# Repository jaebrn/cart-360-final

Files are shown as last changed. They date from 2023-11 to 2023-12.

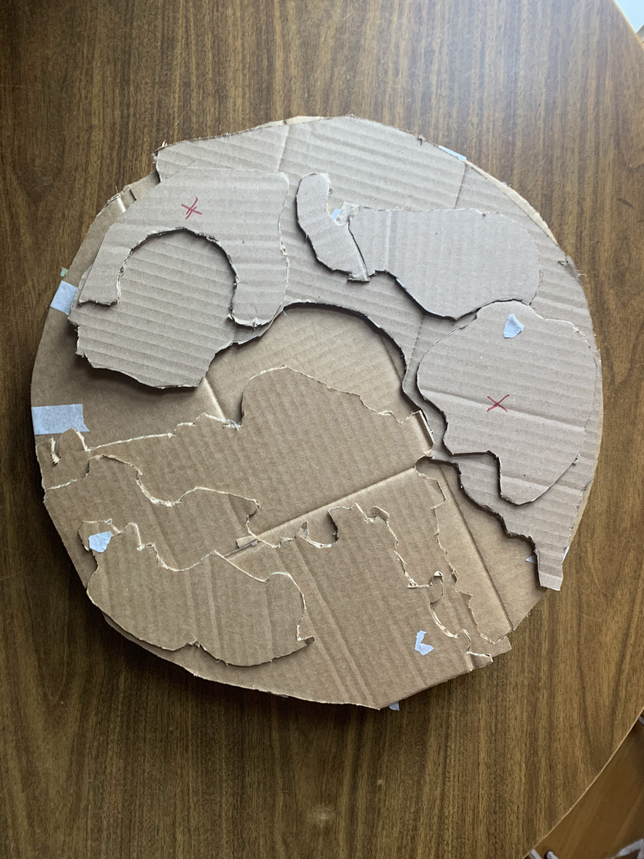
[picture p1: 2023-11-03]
Prototype/Images/Layer_4.jpg

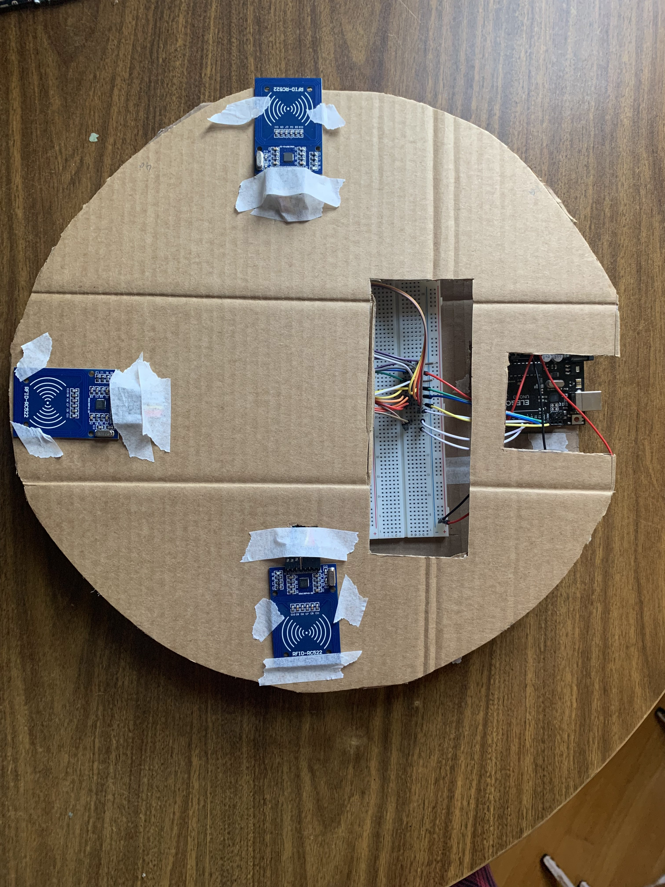
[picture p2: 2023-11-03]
Prototype/Images/Layer_2b.jpg

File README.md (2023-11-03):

# CART 360 Final

This folder includes documentation for an interactive soundscape by Kathryn Lee and Jennifer Brown, 
Completed for CART 360, Concordia University, in Fall of 2023. 

Included are various coding prototypes (progressing chronologically), proposals, sketches, writings, images and sources. 

This project is currently under development. 
Updated November 3, 2023.

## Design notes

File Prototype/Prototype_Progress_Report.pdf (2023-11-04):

# Echoes of the Land:

### Exploring the Soundscape of Pre-Colonial Montreal Through RFID-Enabled Interactive Media

### Prototype Progress Report

Documentation Website (https://github.com/jaebrn/cart-360-final) | Bibliography (https://www.zotero.org/groups/5216653/360-final/library) | Visual Design Document (https://docs.google.com/presentation/d/1SsO0nUtENjOVrvCsT_w7IpJutjQbqw8IsR_H3O8aA6U/edit?usp=sharing)

### Kathryn Lee

Computation Arts Specialization, Concordia University
Montreal, Canada
l_kathry@live.concordia.ca

### Jennifer Brown

Computation Arts Specialization, Concordia University
Montreal, Canada
br_jenni@live.concordia.ca

## Keywords

Emergent Soundscape; Interactive Design; Prototype Development; Radio Frequency Identification; Tangible Media.

## Abstract

Our goal is to create an interactive soundscape representative of pre-colonial Montreal, invoking a desire for exploration, education, and an appreciation of the natural land on which we reside.

This report details the prototyping process to date as we develop our interactive soundscape, entitled Echoes of the Land.

## Ideation, Iteration and Prototyping

Prototyping has been invaluable in our design and production process. While our initial design appeared to us as functional and easily implementable, working with our components and sensors greatly clarified the limitations we work within. Our design has evolved not only to better suit these strengths and restrictions, but to better serve our desired interaction.

Additionally, discussing our designs with others has provided us with crucial feedback, suggestions and critiques. We have learned how a tangible representation enables far greater communication of intention,
and allows for further discussion inaccessible when communicating via words and images alone. The consideration of electronics housing, internal stability, and component accessibility for troubleshooting has similarly been a significant process of ours, enabled and highlighted by the construction of a tangible prototype.

### Division of Labour

Jenna
I primarily focused on the RFID reader setup and related circuitry throughout this project. Much of my focus has been on efficiently organizing multiple readers such that they may be placed easily within the housing, use minimal Arduino pins/breadboard space, and are easily accessible for troubleshooting. Alongside this, I have been coding and experimenting with the MFRC522 Arduino library (https://github.com/miguelbalboa/rfid) (Balboa, 2012). Lastly, I have been working to maintain clean documentation, records of feedback, and citations.

Katt
I focused on the design aspects of the project. While the overall concept was thought of together, I drafted mockups and the logistics with our proposed plan and now revised prototype. I worked on compactly housing all the necessary components and built the initial prototype structure. Additionally, I have been researching other artists’ work to create a living document of our progress and to host references regarding the visual design.

## Sensors and Materiality

### Sensors and Circuitry

Within our prototype, we utilize 3 MFRC522 RFID readers (https://lastminuteengineers.com/how-rfid-works-rc522-arduino-tutorial/) connected to a singular Arduino Uno. We aim to expand this to 6 readers for our final product. As a low-fidelity example of sound output, we utilize a passive Piezo buzzer. All wired components connect to a single breadboard, embedded within the cardboard housing.

Our use of RFID results in the ability to fully obscure circuitry and components within the board. Throughout prototyping, we tested the sensor’s ability to wirelessly receive RFID tag information through varying materials of varying depths. We had great success with their ability to read through non-metallic materials like cardboard and wood up to distances of approximately 1.5 inches. While we plan on developing our final housing structure from wood, any RF-lucent material should serve our function (Payeur). Consequently, our sensors allow for a greater exploration in the visual design of the final result.

Our greatest difficulty in working with the MFRC522 reader was surrounding the implementation of multiple readers within a single microcontroller. This is a common intention amongst those working with these readers, and as such we were able to find several examples of different multi-reader implementation strategies. We primarily referenced Github user Annaane’s implementation (https://github.com/Annaane/MultiRfid) (Annaane, 2019).

Within our prototype, we attach 3 readers to the Arduino, using only 7 pins, not including power and ground, connected via SPI. Each reader uses 4 pins for communication, 2 for power/ground, and one as a reset. The interrupt pin is unused in our context. 3 of the communication pins (MISO, MOSI, SCK), and the reset pin are shared amongst the readers. A final communication pin (SDA) is uniquely connected to the microcontroller for reader identification. As such, we are able to identify the location of a placed tag and read its information. Presently we identify tags via their UID - a unique identifier defined by the tag manufacturer - with the piezo buzzer playing a unique tone for each declared UID when detected.

### Housing and Design

For our prototype, we opted for a table top display. We chose a minimalist approach to a topographical map for the design of the surface. Raised and depressed reliefs mimic the original landscape of the Montreal area. Regarding the visual design of our board and objects, we draw inspiration from Joon Moon (https://www.joonmoon.net/) and Moto Waganari (https://motowaganari.wordpress.com/) who utilize simple silhouettes and shapes within their sculptural works. Waganari is a sculpture artist whose main medium is wire work; Joon Moon is an installation artist who incorporates AR technology with light and shadow to create stunning moving images.

Keeping to the style of the board, the miniatures would take on a more geometric shape. Up until the day of the prototype presentation, it was decided the miniatures would be made out of wire. What was still unclear was how representational they would be in form. Much of our efforts were focused on the board, as it is the central object in our piece.

Given the time we had, the main concerns were with the board itself and how we can effectively communicate our idea without explicitly telling the viewer everything. During this process we tried to keep in mind what someone who has no idea about the concept would do with what we’re presenting them.

## Changes Throughout Development

The core intention of our project - to create an interactive soundscape designed to educate and foster an appreciation for Montreal’s pre-colonial environment - has been maintained throughout development. In this regard, no - our initial intention or meaning has not changed. However, there are of course more fluid elements.

Our initial design surrounded the use of a wall-mounted board to depict the landscape, constructed of a magnetic material allowing for tag-object placement anywhere upon the board. We intended to house RFIC readers underneath this magnetic board, and to visually display the pieces as ‘shadow puppets’, utilizing lighting directed up onto the board. This design includes some notable flaws, such as the RF-opacity of metallic materials and the readers’ lack of radial range (MFRC522’s are strictly effective at reading tags perpendicular to their face) (In-Depth, 2018), (Payeur, 2019). Additionally, the lighting would need to be a guaranteed distance from the tag-objects for the shadow projection to work as intended, and the vertical mounting likely would not have been conducive to our intended interaction and user experience.

Since, we have reconfigured our previous board design to consist of a tabletop piece, constructed of wood, topologically representing the island through layers of precision-cut wood. We have limited the placement options for our tag-embedded objects to a few areas cut to fit the object bases, directly above one of the several RFID readers. This design presents far fewer challenges in working with RFID technology, and allows for more exploration within the visual design of both the board and objects. Similarly, the circular, table-top nature of the design creates a more communal interaction amongst participants, and allows for greater ease of object placement.

## Bibliography

Annaane. (2019, January 19). MultiRfid. GitHub. https://github.com/Annaane/MultiRfid

Balboa, M. (2012, January). Arduino RFID Library for MFRC522. GitHub. https://github.com/miguelbalboa/rfid

Eiche, A. (2010, June 29). A Beginner’s guide to Making an Arduino Shield PCB. AaronEiche.Com.

https://aaroneiche.com/2010/06/24/a-beginners-guide-to-making-an-arduino-shield-pcb/

In-Depth: What is RFID? How It Works? Interface RC522 with Arduino. (2018, July 30). Last Minute Engineers.

https://lastminuteengineers.com/how-rfid-works-rc522-arduino-tutorial/

Ishii, H., Mazalek, A., & Lee, J. (1999). Bottles as a Minimal Interface to Access Digital Information. MIT Media Laboratory.

https://trackr-media.tangiblemedia.org/publishedmedia/Papers/466-Bottles%20as%20a%20minimal/Published/PDF

Ishii, H., Mazalek, A., Lee, J., Fletcher, R., & Paradiso, J. (1999). musicBottles. https://tangible.media.mit.edu/project/musicbottles

Joon Moon 문준용 portfolio. (n.d.). Retrieved November 4, 2023, from https://www.joonmoon.net/

Joseph, J. (2022, May). Interfacing RFID Reader With Arduino. Circuit Digest.

https://circuitdigest.com/microcontroller-projects/interfacing-rfid-reader-module-with-arduino

Lewin, J. (2012). Chandelier Harp. https://www.jenlewinstudio.com/portfolio/chandelier-harp/

MFRC522 Standard performance MIFARE and NTAG frontend. (2016). NXP Semiconductors.

https://www.nxp.com/docs/en/data-sheet/MFRC522.pdf

Miranda, E. R. (2008). Emergent songs by social robots. Journal of Experimental & Theoretical Artificial Intelligence, 20(4),

319–334. https://doi.org/10.1080/09528130701664640

Moto Waganari – artist. (n.d.). Retrieved November 4, 2023, from https://motowaganari.wordpress.com/

Payeur, C. (2019, August 22). RF-Lucent vs. RF-Opaque: Component Materials in RFID Systems. Computype.

https://www.computype.com/blog/the-importance-of-component-materials-when-constructing-rfid-systems/

Smart Lock for an Escape Room: Multi RFID Readers System. (2018, April 23). https://www.youtube.com/watch?v=ahc8Yai_sWI

Tangible, & Wu, J. (2011). jelly swarm.

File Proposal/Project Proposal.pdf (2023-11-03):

# RFID Shadow Project:

Jenna Brown & Katt Lee
Fall 2023 | CART 360 | Concordia University
Documentation GitHub (https://github.com/jaebrn/cart-360-final)

## Project Description

### Overview

The goal of this project is to create a unique, interactive piece of audio-visual public art with emergent sound qualities, reflective of the indigenous environment of Montreal. The heart of the piece is a magnetic board visually representing Montreal. Alongside this, several unique, magnetic objects, each equipped with an RFID tag, may be placed upon the board. These objects will be constructed of precisely cut wood, designed to project a shadow image when placed upon the board, which contains a strip of lighting along its bottom edge.
Each of these objects corresponds to a sound-emitting element found in Montreal throughout its history - including fauna, machinery, and humans. When placed, the board emits a corresponding sound. As objects are added, or removed, and as they remain in contact with the board over time, new and interesting audio qualities emerge, representative of the dependencies and emergent traits which form when various agents exist alongside one another in nature.

### Goal

The goal of this project is to foster within participants an appreciation for Montreal’s native wildlife through means of complex interaction and play. The various systems present within nature can often be depicted on an overly large scale, both spatially and temporally, such that it can be difficult for individuals to gain an appreciation of the elements at play and their relationships to one another. With this interactive soundscape, users can see and hear the effects of their changes in real time, creating a user-friendly model of a very broad concept. With the introduction of man and man-made elements, the project provides a greater understanding of the destructive nature of certain human impulses, while simultaneously depicting that humans themselves can and have peacefully coexisted with nature when a respect for the environment is present and prioritized.
Additionally, the interactive nature of this piece reinforces the power we each have to impart meaningful change - good or bad - on our ecosystem. The viewer is both removed from the depiction of the environment, providing them with a unique overview, while simultaneously given the opportunity to delve within, literally reaching into the landscape and shaping it.

### Audience

This project will likely be placed within a public space at Concordia University, with the target audience being students. Students by nature are curious and learning-focused, while the student body of Concordia is largely composed of out-of-province or international students. As such, the student body of Concordia is assumed to be more likely to interact with an educational art piece, and are more likely to be unfamiliar with the native landscape of Montreal. Alternatively, exiting the scope of the classroom, this project would be ideal in a location such as Montreal’s own Ecomuseum Zoo; (https://zooecomuseum.ca/en/) a conservation and education center surrounding Quebec’s indigenous wildlife.

## Sensors and Equipment

### Radio Frequency Identification (RFID)

The RFID consists of two components; the Tag and the Reader. Each Tag has a distinct UID. RFID Tags are small, inexpensive and easily embedded within a variety of objects. We plan to embed RFID tags within the magnetic, moveable objects, while implementing the reader within the board. We hope to utilize this technology to allow for identification amongst tangible objects connected to unique UIDs, which can then be called to trigger reactions through code.

### Microcontroller

Our project will be coded using the Arduino Uno. This microcontroller has many capabilities and can be used in conjunction with compatible boards such as the NFC reader. Additional positives are that it is small and compact which aids us in hiding the tech behind the experience from the audience.

### Board Composition

Our board will be housing all circuitry and major components used within this project. This includes the Arduino Uno microcontroller board, speakers, and lighting. Speakers will ideally be small and hidden around or within the board, used to play sounds associated with the specific RFID tags embedded within the magnetic objects when placed on the board.

### Magnetic Object Composition

Each moveable, magnetic object consists of a magnetic base, RFID Tag, and a small wooden structure designed to produce a shadow-image depicting the represented environmental element. Magnets allow for these objects to be easily placed and removed from the board, while the RFID tags allow for object identification, corresponding to an emitted sound.

## Interaction Design Strategy

# Project Journeymap

Installation
walkthrough,
features of note
Impact upon viewer | Intended design

The installation is
in a public space.
The main part
seen is the board
at first.

The viewer must confront the artwork. They can walk away or interact.
The installation is noticeable, and viewers are urged to interact.

Fig.1

The fact it is in a public space is inherently confrontational;
Tahe created space should be welcoming. We will investigate how this can be accomplished via the board’s visual design.

The magnets on
the board can be
moved by the user,
magnets cast
shadows on the
board.

The user will either need
instructions by the board or have someone there tell them what to do.
These magnets will look like abstracted forms initially but when placed on the board - their shadows will form the images.

Fig.2.

Generally, we want a smooth interaction between the user and the piece.
When the general public thinks of art installations, they are conditioned not to touch.
We will investigate different methods of explicit and implicit methods of communicating the intended interaction vi

The board reacts
to the user’s
interaction via
sound.

As the user is moving the magnet, it will be detected by the NFC reader attached to the board, which in turn will tell the arduino to play the specific sound attached to that UID of the tag.

Fig 3.

For the viewer to make a
connection to their impact these magnets will be more sculptural in nature. This will make it easy to hold, more accessible if they are more raised and textured.

The sound will come out of two speakers. We will record noises and artificially distort them with digital software to create sounds of flora, fauna and machinery.

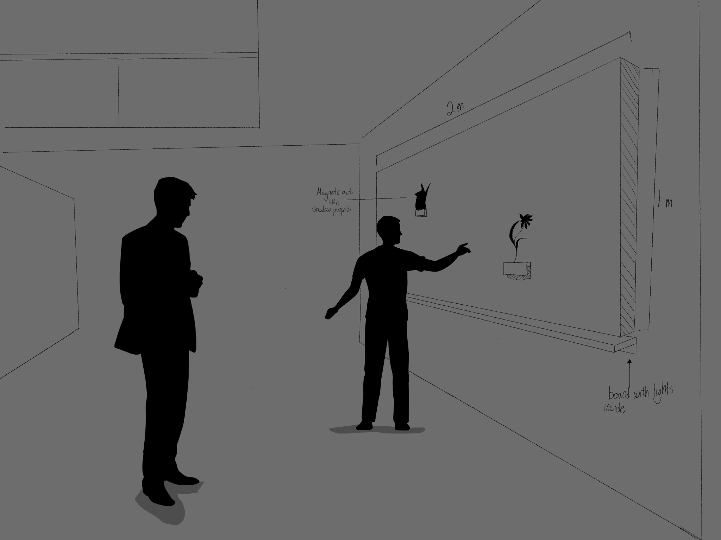
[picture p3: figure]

Fig.1 Example of space.

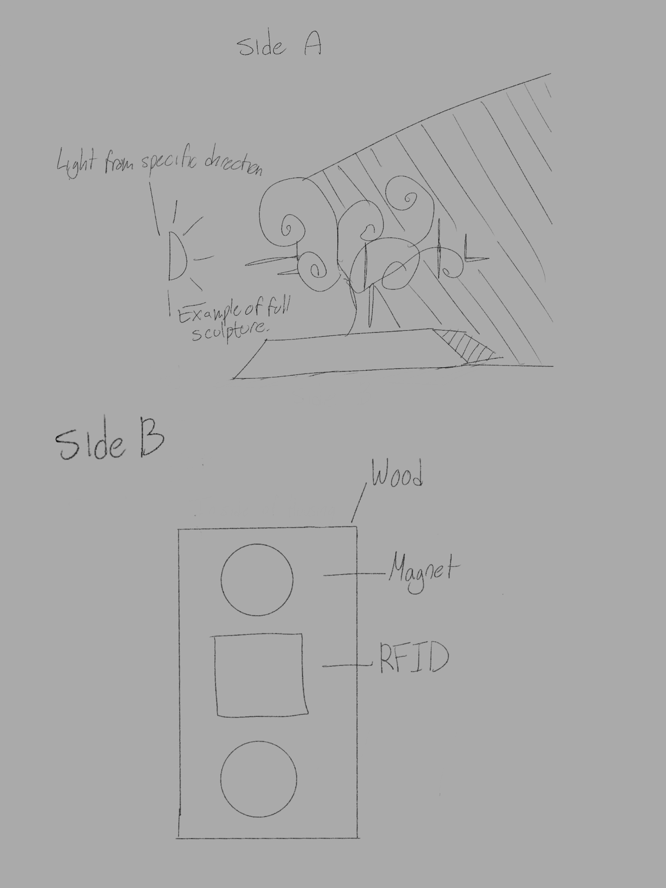
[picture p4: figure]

Fig 2. Composition of magnetic objects.

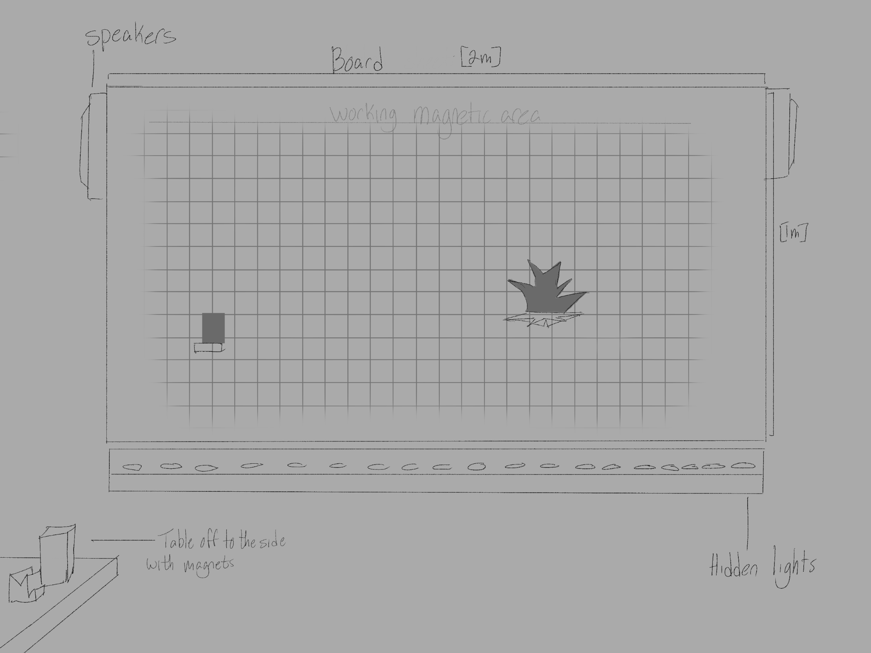
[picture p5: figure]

Fig.3 Board layout (active area, lighting placement, speaker placement).

## Related Projects

Project 1: Chandelier Harp (https://www.jenlewinstudio.com/portfolio/chandelier-harp/) by Jen Lewin

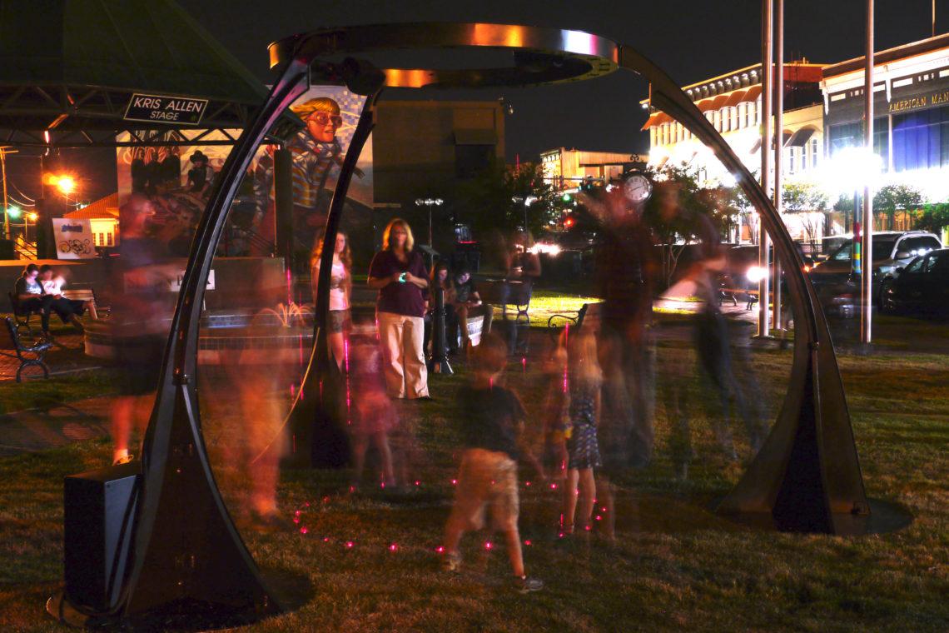
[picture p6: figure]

Chandelier Harp, Jen Lewin (2012). https://www.jenlewinstudio.com/portfolio/chandelier-harp/

Jen Lewin’s Chandelier Harp is an interactive exploration of sound and movement. Most effective with multiple participants, the harp consists of a grand housing structure (or is alternatively hung from a ceiling), and a suspended hoop which emits several low voltage laser beams. When a participant interrupts the beam by moving within the piece, a musical note is produced much like the plucking of a harp chord, with pitch corresponding to movement speed. Chandelier Harp is extremely effective as an interactive art piece. Participants enthusiastically engage with the piece, despite its lack of overt signifiers; the piece communicating itself expertly via its design. This quality is found across much of Lewin’s works, which often take the form of public, interactive art, and we intend to reference this throughout our own creation process. Lewin does a fantastic job of allowing for interesting, emergent interaction and audio outputs from a set of relatively simple parameters. While we reference this success within Chandelier Harp, we also recognize the lack of narrative communicated through interaction. Within our own work, we hope to foster the same potential for playful interaction, expanded to communicate the interaction of distinct and unique agents, aggregating as a narrative.

Project 2: Jelly Swarm (https://www.tangibleinteraction.com/artworks/jelly-swarm) by Tangible, Joseph Wu

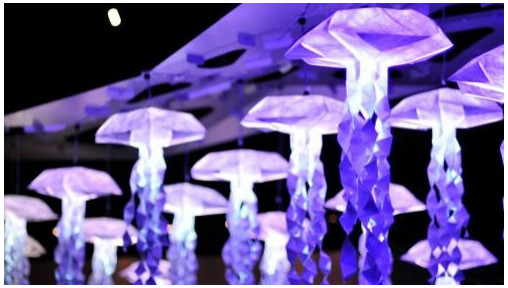
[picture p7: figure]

Jelly Swarm, Tangible & Joseph Wu, (2011). https://www.tangibleinteraction.com/artworks/jelly-swarm

Created by new media collaborative Tangible and origami artist Joseph Wu, Jelly Swarm, was designed to teach broad concepts surrounding jellyfish communication and bioluminescent properties. Hosted within the Vancouver aquarium in 2011, these ceiling-suspended origami jellyfish are equipped with various sensors, illuminated by color changing lights. Interaction between the viewer and piece occurs via remote controller, with which the participant is able to disturb an area of the swarm, prompting a change in lighting originating in that area; mimicking the natural bioluminescence of the jellies. When no participant disruptions are occurring, the lighting evolves of its own accord, flowing throughout the piece to mimic swarm proximal communication.
While, like our proposed project, this piece explores naturally occurring concepts and phenomena in a novel, interaction-oriented manner, the swarm’s system of interaction is substantially more linear and removed than our intended system. While the use of a remote controller is practical - the jellies are delicate and suspended - its use results in an added level of removal between the piece and participant, and prevents a truly hands-on approach. Additionally, this piece operates truly as a swarm: a substantial collection of principally identical objects, behaving in identical ways; with the sense of evolution or change originating from a positive correlation between proximity and time required for communication between agents. Contrasting this, each element in our piece will behave differently, being uniquely identifiable. In this use, the sense of evolution derived from the ways in which these unique agents interact with one another.

Project 3: musicBottles (https://tangible.media.mit.edu/project/musicbottles/) by MIT Media Laboratory, Hiroshi Ishii et al.

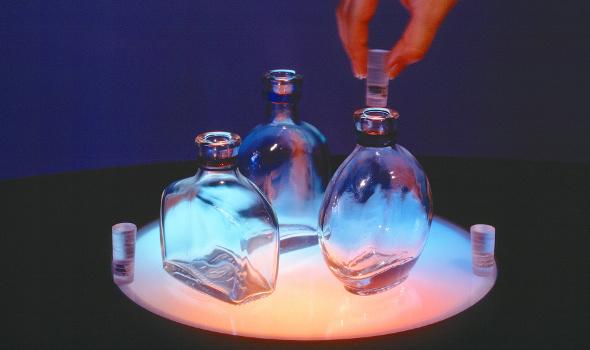
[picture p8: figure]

musicBottles, Hiroshi Ishii et al. via MIT Media Lab. (1999) https://tangible.media.mit.edu/project/musicbottles/

musicBottles, a research-creation work led by Hiroshi Ishii of the MIT Media Lab, explores unique sensors and sound production techniques. The project consists of a deceptively complex custom table, housing electronic equipment, with a series of corked bottles placed atop. Each bottle corresponds to a different instrument, and is embedded with a unique electromagnetic tag which wirelessly identifies (while placed on the table) whether the bottle is corked. Bottles are freely moveable, and when uncorked, ‘release’ their contained sound. The table is additionally equipped with dynamic lighting, which reacts to changes in pitch and volume.
The novel sensors and atypical inputs are of particular interest in relation to our
proposed project. Our current intention is in utilizing RFID sensors, though it’s important to consider alternatives and backups. There is quite detailed documentation on the construction of these tags and sensors, which may be of use to our development. Regarding interaction and the user’s experience, while this project produces a comparable end result to our proposed project (use of atypical objects to prompt the production of sound), musicBottles are actually quite static. The audio emitted simply corresponds to a portion of a song, and the interaction is quite binary; corked or uncorked, off or on. In contrast, we hope to create a work fostering emergent auditory properties, a communicated concept/narrative, and deeper, more meaningful user interaction.

## Conclusion

In conclusion, we aim to create an interactive audiovisual art piece with emergent audio qualities responsive to participant interaction. We aim to communicate the desired interaction implicitly through the piece’s design, and hope to create an experience which challenges the user to critically analyze the effects their actions can have on their environment. We hope similarly to foster through our piece a curiosity and appreciation for the wildlife indigenous to Montreal and Quebec.

## Works Cited

Ishii, H., Mazalek, A., & Lee, J. (1999). Bottles as a Minimal Interface to Access Digital

Information. MIT Media Laboratory.

https://trackr-media.tangiblemedia.org/publishedmedia/Papers/466-Bottles%20as%20a%20mi

nimal/Published/PDF

Ishii, H., Mazalek, A., Lee, J., Fletcher, R., & Paradiso, J. (1999). musicBottles.

https://tangible.media.mit.edu/project/musicbottles

Joseph, J. (2022, May). Interfacing RFID Reader With Arduino. Circuit Digest.

https://circuitdigest.com/microcontroller-projects/interfacing-rfid-reader-module-with-arduino

Lewin, J. (2012). Chandelier Harp. https://www.jenlewinstudio.com/portfolio/chandelier-harp/

Miranda, E. R. (2008). Emergent songs by social robots. Journal of Experimental & Theoretical

Artificial Intelligence, 20(4), 319–334. https://doi.org/10.1080/09528130701664640

Our Animals | Ecomuseum Zoo. (n.d.). https://zooecomuseum.ca/en/animals/

Tangible, & Wu, J. (2011). jelly swarm.

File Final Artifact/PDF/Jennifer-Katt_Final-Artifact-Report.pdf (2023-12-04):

## Echoes of the Land:

### RFID-Powered Interactive Soundscape Inspired by Pre-Colonial Montréal

Primary Documentation Website: https://github.com/jaebrn/cart-360-final

### Jennifer Brown

Computation Arts Specialization Concordia University, Montréal br_jenni@live.concordia.ca

### Katt Lee

Computation Arts Specialization Concordia University, Montréal l_kathry@live.concordia.ca

ABSTRACT
This report presents our exploration in creating a tangible interactive soundscape representative of pre-colonial Montréal. We investigated the use of radio-frequency identification (RFID) readers and tags as sensing components indicating the placement of unique objects atop a topological representation of Montréal; each object provoking sound associated with the flora and/or fauna of the island. Through this, we explored methods of enhancing the user experience, considering materiality, form, and audio-visual enhancements.

INTRODUCTION
Designed as a tabletop educational public art display, this project consists of two distinctly categorized elements; the board, housing circuitry and RFID readers, forming a topological representation of the island of Montréal pre-colonization; and the objects, each housing an RFID tag, representative of an element of Montréal’s natural flora and/or fauna. Objects, at users’ discretion, may be placed within one of several circular indentations within the housing board. Each indentation is located atop an RFID reader. Upon placement, the tag is assessed by the correlating reader, and audio is played corresponding to the tag’s unique identifier (UID).

This project’s intention is to highlight how our environments have changed throughout the years as a result of colonization and human activity. Echoes of the Land plays on how the surrounding environment is often seen as an object to serve industrialization, and the ways in which this impacts the collective memory of the past. This project reminds us to be conscious of our surroundings while educating newcomers to Montréal of the indigenous wildlife that has survived to the modern day.

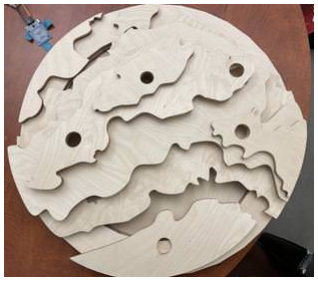
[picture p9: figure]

Figure 1: Housing Board: RFID reader embedded topological representation of Montréal.

INTERACTION
Our intent was to create a public installation to bring together environmental awareness as well as provide an enriching experience to the user. The user would place the objects onto the board. The board would then react to the object being identified to play the sound depicted in the wire sculpture. Whether that be an animal or plant. When the object would be placed, an led embedded below would glow as a presence was detected. Within the board would house lights that would blink in and out in a way to mimic water patterns.

MATERIALS & DESIGN
Board
Materials were deeply important to the success of this project, both functionally and narratively. RFID signals are likely to be interrupted by the use of certain materials (primarily metals) deemed RFID-opaque (Payeur, 2019). We experienced minimal interruptions in reading through plant based materials such as wood, paper, and cardboard, with tag sensing capabilities reaching distances of approximately two inches through these materials. In considering the themes of environmentalism within this project, synthetic and unsustainable materials were avoided. As such, we opted to construct the housing from wood.

We created a number of vector files for each topological layer, referencing current and historic maps, and research regarding the island's changing landscape (Figure 3). These files were then input via CNC machine to produce the precise shapes contributing to topology (Figure 1).

We looked at old maps of montreal to see what islands were still included, which were renamed, and based the shape of our project off those photos (Figure 2).

When creating the design for the board it was important to somewhat abstract the form of the island. To make sure that it was visually appealing but still thin enough for the readers to read through the wood, small holes were placed throughout the board on different levels. Most of the board was based on the surrounding area of Mont Royal as it had the most topographic variation, and significant diversity in natural wildlife. We thought it would be interesting to reimagine the finer details while leaving the prominent landmarks we still see today. Due to using the CNC machine, many of the edges needed to be adjusted to be cut by its ⅛” cutter without issues.

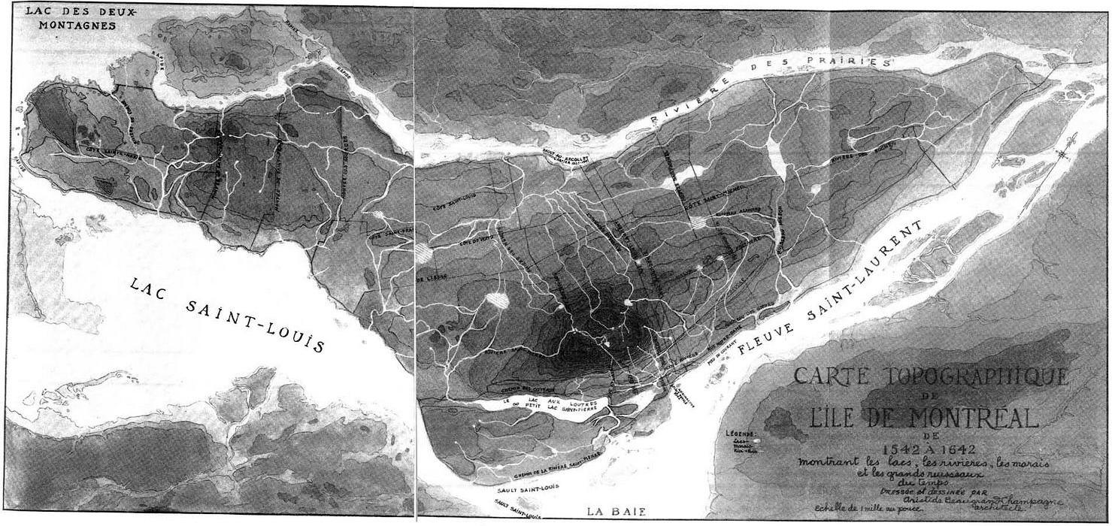
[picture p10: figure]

Figure 2: Old map of montreal depicting rivers which for some do not exist currently Credits: https://spacing.ca/montreal/2009/10/29/montreals-rivers/

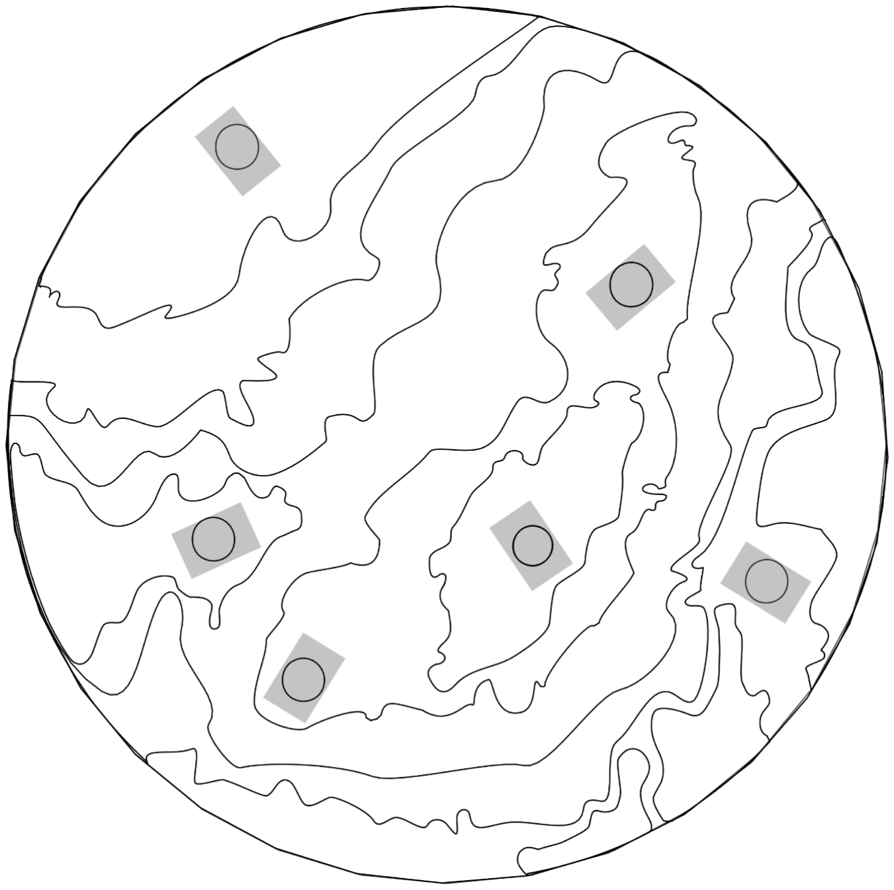
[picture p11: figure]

Figure 3: Layered Housing Board vector files, depicting RFID readers and tag indentations for placement.

Objects: Concept
In line with our concept, the objects that were created symbolized different aspects of the wildlife found natively in Montreal. These were made of wire and cardboard. We wanted these objects to convey the industrialisation of the land by incorporating more man made materials into the pieces being physically handled by the audience. The objects create an interaction with the narrative itself, of how we change the landscape we inhabit. (Figure 4)

Objects: Animals
To provide a wider range of sounds to the soundscape we created mammals, fish, and plants. These objects were based on animals such as the Red Fox, the Smallmouth bass, an Eastern Cottontail rabbit, and a River Otter as well as plants like the provincial flower The Iris Versicolor. All these animals could be found on the Mont Royal website as well as multiple sources of Quebec wildlife.

Objects: Housing and Tags
Within the bottom of the objects, there was a container created from cardboard which housed the RFID tag. Using the tags provided from the kit, we found that it was too large to fit inside the openings in the board. In the end, we disassembled the tags and twisted the copper wire perimeter to size them down. After testing the tags to verify they were functional they were then glued to the bottom and the wire sculpture was attached to the top of the box. (Figure 5 )

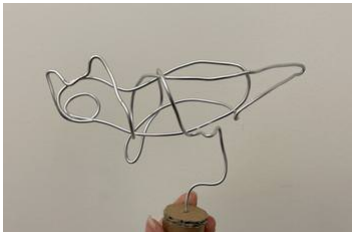
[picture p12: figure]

Figure 4: Example of object: pictured River Otter Object

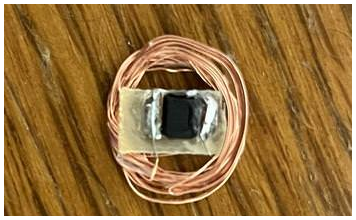
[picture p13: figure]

Figure 5. Modified RFID Tag within object housing

HARDWARE
Radio Frequency Identification: Readers
While our final housing unfortunately only contained five readers due to a vector file error, our circuitry functionally supported six RC522 readers operating from a single Arduino Uno. This was accomplished by splitting all but one of the seven pins used by each RC522 reader utilized for power and SPI communications. Several of these pins (such as SCK, MOSI and MISO reader pins) require access to components within the Arduino Uno microcontroller board, accessible only via certain digital input/output pins. As such, to operate multiple readers from a single board, pins such as this must be shared amongst readers (In-Depth, 2018). (Figure 6)

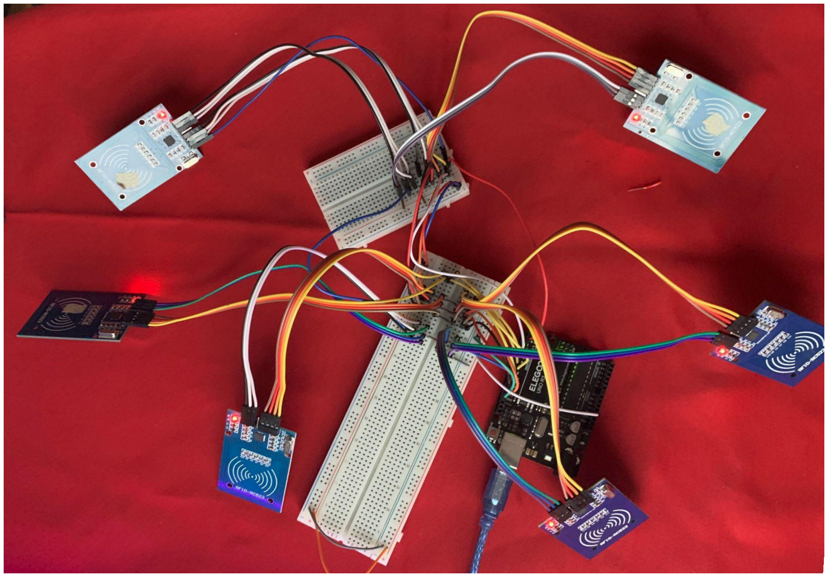
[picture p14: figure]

Figure 6: Prototyped RFID reader circuit, supporting six readers.

Radio Frequency Identification: Tags
The RC522 modules utilized within this project are accompanied by a 13.56MHz tag (Figures 7, 8). To house them, we removed the outer plastic and embedded solely the coil and inner tag within our identifiable objects. (Figure 5) While the separated inner tag was easily read by the reader, we experienced interference when attempting to read the inner tag housed within the object’s themselves.

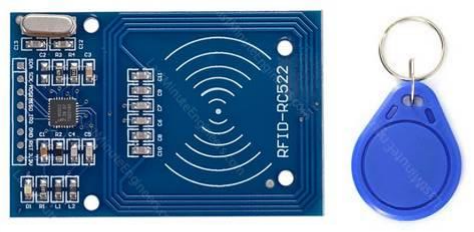
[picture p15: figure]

Figures 7,8: RC522 RFID Reader Module & 13.56MHz RFID Tag Image credits: Last Minute Engineers (https://lastminuteengineers.com/how-rfid-works-rc522-arduino-tutorial/)

Audio-Visual Components
Accompanying the RFID system, our circuitry supports a number of LEDs, designed to be embedded within the housing board indentations, illuminating upon the placement of a recognized RFID tag. We initially hoped to include internal components and circuitry to support audio production. Ultimately, we maintained connection between the Arduino Uno and an external PC, playing audio from the PC’s disk, over its speakers.

Housing & Wiring
The housing design was created in Blender, a 3D modeling software, using vertex points converted into grease pencil. Blender was used after multiple attempts in Adobe Illustrator to turn sketches created with another drawing program into vector layers. It was challenging to estimate scale and anticipate what would be needed and what could be done with the CNC machine.

SOFTWARE
Our artifact operated using two software platforms; Arduino IDE, and Max 8. Arduino was used for the internal circuitry; lighting, reader operations, and logic regarding object placement. Max was used solely for audio output from an attached PC, with output correlating to Arduino IDE’s RFID readings.

Standard communications using the RC522 was accomplished with the use of two libraries; MFRC522 (https://github.com/miguelbalboa/rfid) (for operations utilizing the reader’s MFRC522 chip) and SPI (https://www.arduino.cc/reference/en/language/functions/communication/spi/) (for communications between readers and the Arduino Uno microcontroller) (Balboa, 2012) (SPI -Arduino Reference, n.d.). Our initial code was heavily inspired by Github user Annaane’s multi RFID (https://github.com/Annaane/MultiRfid) setup, also utilizing the RC522 module (Annaane, 2019).

A majority of the logic concerning object and reader identification was developed using arrays. There are several arrays within the code, containing the readers, the recognized UIDs, and integers reflecting the state (on/off) of each object associated with a recognized UID. Though unused in this context, the program also recognizes the location of objects amongst the readers, should audio be implemented with multiple sources.

The program assesses each RFID reader within an offset loop, as our use of pin splitting prevents readers from being assessed simultaneously. When a recognized UID is received by an RFID reader, an integer numbering 1-5 (associated with each of the five tagged objects) is written to the serial output. When a recognized UID previously received by a reader is no longer present upon that reader, a corresponding integer numbering 6-10 is subsequently written to serial.

Within Max, the same serial is read. Upon an incoming integer 1-5, the associated audio channel is activated; upon incoming integer 6-10, that same associated channel is deactivated, producing a responsive audio output. Similar logic is utilized within Arduino IDE to produce LED illumination at the reader receiving a recognized UID.

DIVISION OF LABOUR
Jennifer
My work consisted of three primary areas throughout this project: woodworking, circuitry, and code. My initial focus was on developing a circuit configuration to support six RFID readers. Alongside this, I developed the circuitry to support RFID reading correlating lighting, handled internally by the Arduino Uno.

I continued developing code to support our function of reading multiple RFID outputs and identifying various tag UIDs. To this effect, I created a loop which determines the state of each reader at offset intervals. Readers are unable to be read simultaneously due to their pin splitting. With this, I created a function to produce an integer correlating to the initial placement and removal of the identified UID, to be utilized by Max to produce a corresponding audio output.

I additionally produced the wooden components of the housing; using a CNC machine to create precisely cut wooden pieces via Katt’s vector files. I then sanded the pieces, removing the connective layers of wood. Due to vector sizing errors and a missing vector file, I returned to the woodshop to remove some additional pieces of the housing layers to make room for the circuitry and components.

Katt
My work was mainly focused on the objects, code for a wave pattern with RGB string lights, the creation of the housing design and constructing it together within the housing.
The vector files used consisted of multiple layers that had to be individually made from a sketch I had done previously. Scale was an issue as I am not familiar with how to create images for the CNC machine. I tried my best to approximate scale and provide a reference image. However there were still issues during cutting that I had no time to redo.

The wire objects were hand bent and assembled with the hopes of 3D printing a more secure housing on the bottom. Since the cutouts for the objects on the board were varying sizes, cardboard was used instead. As well, I learned the FASTLED library to create patterns with LEDs.

Afterwards when I had finished making the objects, the code, I was tasked with assembling it together. My original plan was to solder the wires together, splitting the shared wires into 6 ways each as well as having separate wires for the SDA pins. Without extra readers and limited time soldering was not a viable option at the time. Instead I attached the readers with extra jumper cables to extend their reach, as well as creating space within the housing to account for the breadboard’s height with cardboard spacers.

PROTOTYPING
Board
During our prototyping phase many considerations were made with the layout and interaction design. The board was constructed out of cardboard, allowing us to cut holes as needed without difficulty. In the end more space was required for the components and layers were added to accommodate the size (Figures 9, 10).

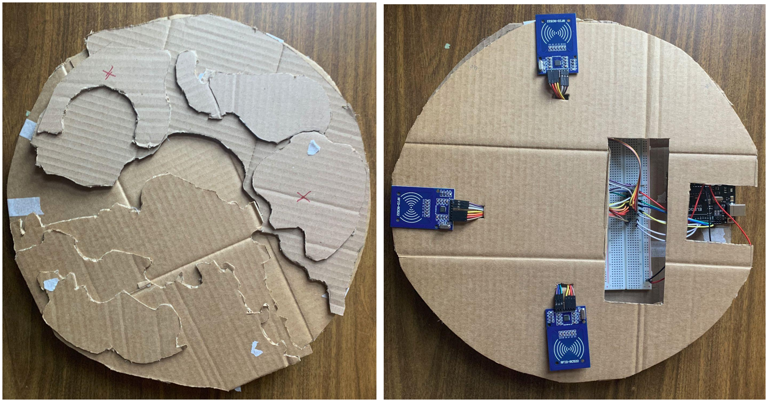
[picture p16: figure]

Figures 9, 10: Cardboard prototype, upper layer (left) and internal housing (right).

Objects
During this time object prototypes were made of varying materials, such as EVA foam and paper. With both materials while the objects looked sleek and clean there were concerns about structural integrity and durability. The initial idea was to have hollow objects that could be lit with LEDS from the inside. We had concerns whether the extra LEDS within the objects would create interference. foam/paper models were not viable for the final artifact. With the fragility and limitations with lighting, the material was changed.

ARTIFACT
The final artifact contained within, 4 functional readers, and 5 separate objects that could be detected. While not everything had been completed fully compared to the goals set out for the project, the main components were present which effectively portrayed the intent.

OBSERVATIONS
There were plans to have everything to power and create sound in the board with no external connections, with the power requirements of the board we found it less feasible for it to all be housed inside. Plans were made to have lighting connected to a separate arduino which would control the ambient lighting to mimic water underneath a layer of cloth.
Unfortunately due to time constraints, these goals were not fully realized. On the day of the presentation we received many connection issues due to poor connectors. Many of our objects were detected by select readers as opposed to all of them. With time we hope these bugs could be fixed. The lighting for the water was also not present during the final presentation. With time we hope to add it later to the board.

FUTURE DIRECTIONS
In continuing this project, several elements require further attention or reworking. Primarily, it would be a significant improvement should the artifact operate unattached to an external PC. For this, the use of an additional Arduino audio module is required, as well as the use of external speakers. Furthermore, an internal power source would be required.

Though our code supports dynamic RFID-triggered lighting, further structure is required within the housing to best support these components. Similar alterations to the housing would improve the fidelity of the resulting artifact, such as an impermanent (yet stable) method of layer assembly, (providing access to the circuitry for troubleshooting if required) and a reconfiguration of the internal circuit housing to properly fit the size of our components. Further emphasis could be applied upon the visuals of the housing, such as adding a stain or varnish to the wood, or using a more thematically relevant species of wood (i.e. wood from trees naturally occurring within Montréal. Reconfiguration of the reader location, soldered internal wiring (as opposed to stringed jumper wires) and higher fidelity RFID tag housing are also needed to further the consistency of the artifact’s functionality.

Narratively, our artifact is designed as an informative public art display, representing a non-colonial perspective on the wildlife of Montréal. To this effect, additional information could be supplied to users (for example, an LCD screen within the board communicating information regarding the flora/fauna represented by the objects, and the representative locations within the board: e.g., “Red fox to the North…”).

It is imperative to note that neither author identifies as Indigenous. Regarding the themes and narratives, the inclusion of Indigenous perspectives is crucial in the continuation of this project. While we make significant effort to remain accurate in our depiction of a pre-colonial Montréal, increased communication and representation of the communities historically centered upon this land is invaluable.

REFERENCES
Annaane. (2019, January 19). MultiRfid. GitHub. https://github.com/Annaane/MultiRfid
Balboa, M. (2012, January). Arduino RFID Library for MFRC522. GitHub. https://github.com/miguelbalboa/rfid
Eiche, A. (2010, June 29). A Beginner’s guide to Making an Arduino Shield PCB. AaronEiche.Com. https://aaroneiche.com/2010/06/24/a-beginners-guide-to-making-an-arduino-shield-pcb/
In-Depth: What is RFID? How It Works? Interface RC522 with Arduino. (2018, July 30). Last Minute Engineers. https://lastminuteengineers.com/how-rfid-works-rc522-arduino-tutorial/
Ishii, H., Mazalek, A., & Lee, J. (1999). Bottles as a Minimal Interface
to Access Digital Information. MIT Media Laboratory. https://trackr-media.tangiblemedia.org/publishedmedia/Papers/466-Bottles%20as%20a%20minimal/Published/PDF
Ishii, H., Mazalek, A., Lee, J., Fletcher, R., & Paradiso, J. (1999). musicBottles. https://tangible.media.mit.edu/project/musicbottles Joon Moon 문준용 portfolio. (n.d.). Retrieved November 4, 2023, from https://www.joonmoon.net/
Joseph, J. (2022, May). Interfacing RFID Reader With Arduino. Circuit Digest.
https://circuitdigest.com/microcontroller-projects/interfacing-rfid-rea der-module-with-arduino
Lewin, J. (2012). Chandelier Harp. https://www.jenlewinstudio.com/portfolio/chandelier-harp/
MFRC522
Standard performance MIFARE and NTAG frontend. (2016). NXP Semiconductors.
https://www.nxp.com/docs/en/data-sheet/MFRC522.pdf

Miranda, E. R. (2008). Emergent songs by social robots. Journal of Experimental & Theoretical Artificial Intelligence, 20(4), 319–334. https://doi.org/10.1080/09528130701664640
Moto Waganari – artist. (n.d.). Retrieved November 4, 2023, from https://motowaganari.wordpress.com/
Nature on Mont royal (2023), https://www.lemontroyal.qc.ca/en/nature-on-mount-royal Montreals rivers (2009), Spacing.ca https://spacing.ca/montreal/2009/10/29/montreals-rivers/
Payeur, C. (2019, August 22). RF-Lucent vs. RF-Opaque: Component Materials in RFID Systems. Computype. https://www.computype.com/blog/the-importance-of-component-materials-when-constructing-rfid-systems/
Smart Lock for an Escape Room: Multi RFID Readers System. (2018, April 23). https://www.youtube.com/watch?v=ahc8Yai_sWI SPI - Arduino Reference. (n.d.). Retrieved December 3, 2023, from https://www.arduino.cc/reference/en/language/functions/communication/spi/
Tangible, & Wu, J. (2011). jelly swarm.

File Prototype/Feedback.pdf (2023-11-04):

# Proposal Feedback: CART 360

## October 19, 2023 : Meeting with Elio

### Mounting

- Why opt for a board on the wall?
- Wall mounting could cause additional difficulties (height accessibility, awkward interaction of reaching up causing arm strain…)
- Wall mounting limits the potential interactions
- Why not tabletop?
- A tabletop structure could emphasize the desired interaction
- An area for people to gather, see: storytelling, hearth, conversation, oral history
- Additionally reduces issues with accessibility
- Allows for increased investment from the user
- Would also allow for more interesting or delicate visual design, various potential materials and forms

### Form

- Why not a circular board?
- Allows for equal distancing from the board perimeters
- Reinforces the themes of nature, community, land
- Perhaps it could mimic a topological map of the island…

### Sensors

- For an rfid reader to have appropriate range, a custom rfid antenna with hundreds of rounds of wire going along the range perimeter
- Many readers require tag placement right on top of the reader for it to be picked up
- Also note materials exist on a scale of RFID lucidity, from opaque to lucid. Lucidity of the material dividing the reader and tag is required for communication.
- Alternative option 1:
- Larger objects with microcontrollers inside, communicating using I2C comms
- On placement, they access power and I2C channels, announcing themselves on the board. Location cannot be assessed, but unique ID
- Option 2:
- Inside the objects, place an infrared LED blinking at different frequencies. Mount an IR camera pointing at the board from the ceiling. Map the area and board perimeters, and identify the location of the objects by searching for the location of their particular blinking pattern.

- Most complicated, but allows for object location determination
- Interruptible signals and finicky detection
- Option 3:
- Physical connection via audio jacks embedded in the board and objects

### Audio

- What if: speak and spell, instead of direct representative animal sounds, maybe digital voice replication? Animal sounds made by humans. Leave room for creativity. Overly representational sounds may not spark the feeling/interaction thats desired
- Think about how different people are going to interact. Encourage playful interaction

## November 2: Prototype Presentation Feedback

- See Adafruit lights for interesting & inexpensive RGB setups
- https://www.adafruit.com/category/37
- See digikey for small RFID tags/capsules to embed in objects
- Be sure to check the emission frequency – must match that of the reader
- https://www.digikey.ca/en/products/filter/rfid-transponders-tags/853
- Board design: research the landscape of pre-colonial Montreal (there are certain natural structures like rivers which have since disappeared)
- Object design: experiment with greater abstraction and various materials
- Abstraction increases the drive to interact

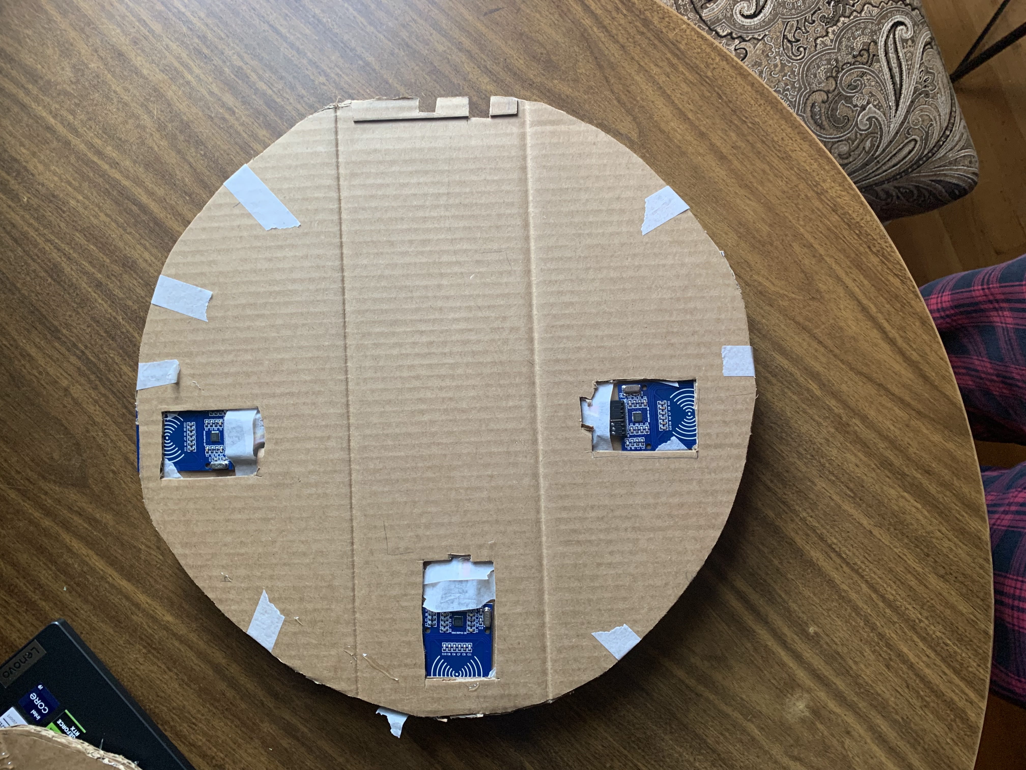
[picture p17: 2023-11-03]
Prototype/Images/Layer_3.jpg

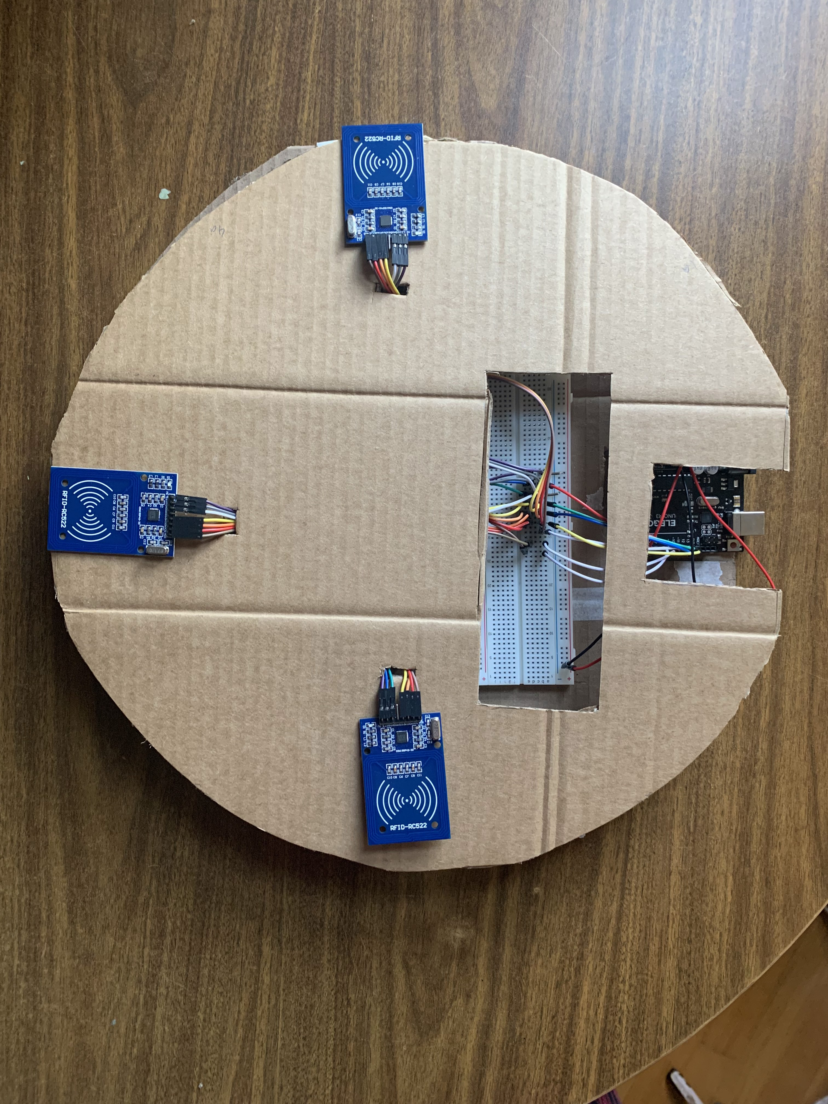
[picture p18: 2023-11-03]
Prototype/Images/Layer_2a.jpg

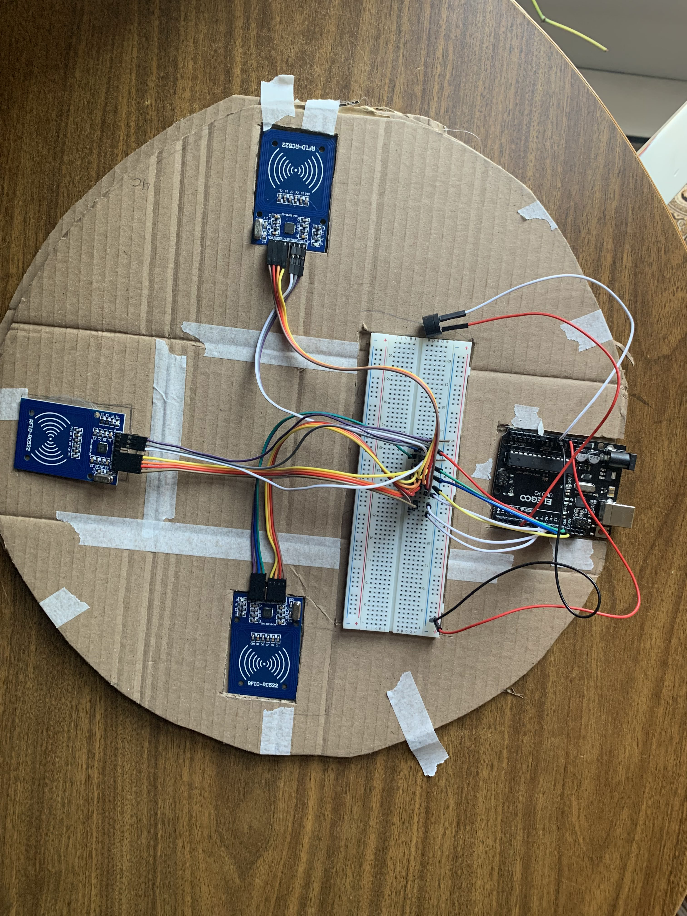
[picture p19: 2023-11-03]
Prototype/Images/Layer_1.jpg

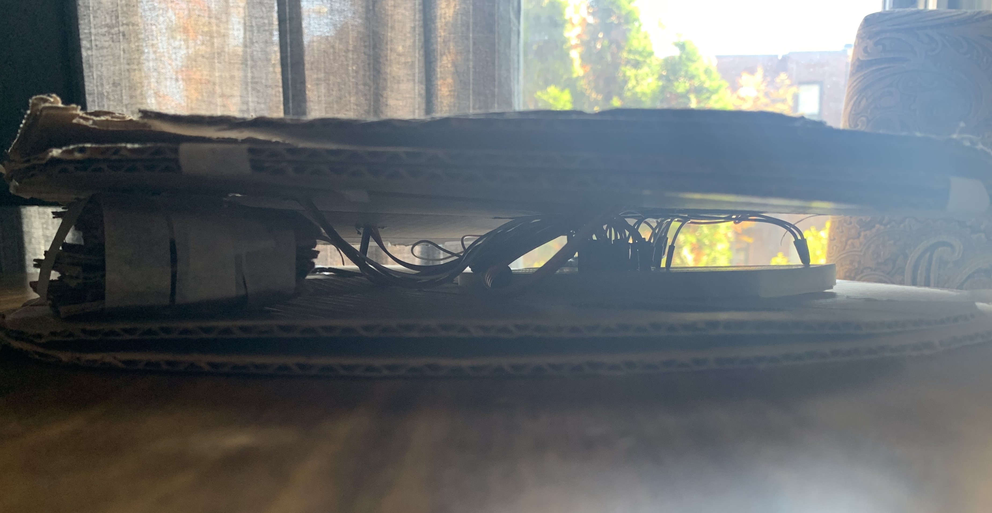
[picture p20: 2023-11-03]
Prototype/Images/Side_View.jpg

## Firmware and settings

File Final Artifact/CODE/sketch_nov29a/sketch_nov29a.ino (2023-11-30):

/**
   --------------------------------------------------------------------------------------------------------------------
   MULTI-RFID : MFRC522 
   Katt Lee & Jenna Brown
   CART360 Final Project : Echoes of the Land 
   An RFID-Powered Interactive Soundscape of Pre-Colonial Montreal
   --------------------------------------------------------------------------------------------------------------------
   This is created referencing a MFRC522 library example; for further details and other examples see: https://github.com/miguelbalboa/rfid

   Pin layout used:
   -----------------------------------------------------------------------------------------
               MFRC522      Arduino       Arduino   Arduino    Arduino          Arduino
               Reader/PCD   Uno/101       Mega      Nano v3    Leonardo/Micro   Pro Micro
   Signal      Pin          Pin           Pin       Pin        Pin              Pin
   -----------------------------------------------------------------------------------------
   RST/Reset   RST          9             5         D9         RESET/ICSP-5     RST
   SPI MOSI    MOSI         11 / ICSP-4   51        D11        ICSP-4           16
   SPI MISO    MISO         12 / ICSP-1   50        D12        ICSP-1           14
   SPI SCK     SCK          13 / ICSP-3   52        D13        ICSP-3           15

*/

#include <SPI.h>
#include <MFRC522.h>

// PIN Numbers : RESET + SDAs
#define RST_PIN         9
#define SS_1_PIN        10
#define SS_2_PIN        8
#define SS_3_PIN        7
#define SS_4_PIN        6
#define SS_5_PIN        4
#define SS_6_PIN        2

byte ledPins[] = {A0, A1, A2, A3, A4};


#define NR_OF_READERS   4
//#define MFRC522_SPICLOCK SPI_CLOCK_DIV10	//If having problems, try different values here. 
byte ssPins[] = {SS_1_PIN, SS_2_PIN, SS_3_PIN, SS_4_PIN}; //match reader count

// Create an MFRC522 instance :
MFRC522 mfrc522[NR_OF_READERS];

//values for PICC_WakeupA
byte bufferATQA[2];
byte bufferSize = sizeof(bufferATQA);

static String definedKeys[] = {"D918CAC2", "7CBBB30"};
static String keyValue[] = {"cat", "dog"};
byte currentKeys[] = {};
String reading = ""; // incoming UID

void setup() {
  //Initialization:

  Serial.begin(9600);           // Initialize serial communications with the PC
  while (!Serial);              // Do nothing if no serial port is opened (added for Arduinos based on ATMEGA32U4)

  SPI.begin();                  // Init SPI bus

  /* looking for MFRC522 readers */
  for (uint8_t reader = 0; reader < NR_OF_READERS; reader++) {
    mfrc522[reader].PCD_Init(ssPins[reader], RST_PIN);
    Serial.print(F("Reader "));
    Serial.print(reader);
    Serial.print(F(": "));
    mfrc522[reader].PCD_DumpVersionToSerial();
  }

  for(int i = 0; i < 5; i++){
    pinMode(ledPins[i], OUTPUT);
    digitalWrite(ledPins[i], LOW);
  }
}

void loop() {

   for (uint8_t reader = 0; reader < NR_OF_READERS; reader++) { //looping through each reader
if(mfrc522[reader].PICC_IsNewCardPresent() && mfrc522[reader].PICC_ReadCardSerial()){ // if a card is present..
    //Print UID info
       reading = ""; // cleared reading

      for (int i = 0; i < mfrc522[reader].uid.size; i++) { 
        reading.concat(String(mfrc522[reader].uid.uidByte[i], HEX)); // concat'ing incoming data into single string
      }
      reading.toUpperCase();
      Serial.print(reading);
      for(int i = 0; i < sizeof(definedKeys); i++){
        if (reading == definedKeys[i])
        {
          Serial.println();
          Serial.print(keyValue[i]);
          digitalWrite(ledPins[reader], HIGH);
        }
  }
       
      // dump_byte_array(mfrc522[reader].uid.uidByte, mfrc522[reader].uid.size);
       Serial.println();
       mfrc522[reader].PICC_HaltA();
       
    }   
    else if(mfrc522[reader].PICC_WakeupA(bufferATQA, bufferSize) && mfrc522[reader].PICC_ReadCardSerial()){ // if a card is present..
    //Print UID info
       reading = ""; // cleared reading

      for (int i = 0; i < mfrc522[reader].uid.size; i++) { 
        reading.concat(String(mfrc522[reader].uid.uidByte[i], HEX)); // concat'ing incoming data into single string
      }
      reading.toUpperCase();
      Serial.print(reading);
      for(int i = 0; i < sizeof(definedKeys); i++){
        if (reading == definedKeys[i])
        {
          Serial.println();
          Serial.print(keyValue[i]);
          digitalWrite(ledPins[reader], HIGH);
        }
  }
       
      // dump_byte_array(mfrc522[reader].uid.uidByte, mfrc522[reader].uid.size);
       Serial.println();
       mfrc522[reader].PICC_HaltA();
    }else{
      digitalWrite(ledPins[reader], LOW);
    }   
   }
  }


/**
   Helper routine to dump a byte array as hex values to Serial.
*/
void dump_byte_array(byte * buffer, byte bufferSize) {
  reading = ""; // cleared reading

  for (byte i = 0; i < bufferSize; i++) { 
    reading.concat(String(buffer[i], HEX)); // concat'ing incoming data into single string
  }
  reading.toUpperCase();
  Serial.print(reading);
  verifyUID();
}

void verifyUID(){ // compares incoming reading to array of known UIDs
  for(byte i = 0; i < sizeof(definedKeys); i++){
    if (reading == definedKeys[i])
    {
      Serial.println();
     Serial.print(keyValue[i]);
    }
  }
}

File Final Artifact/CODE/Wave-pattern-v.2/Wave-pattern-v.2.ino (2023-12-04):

#include <FastLED.h> //Library used https://github.com/FastLED/FastLED
#define NUM_LEDS 60 //number of leds in strip 

CRGBArray<NUM_LEDS> leds;
//                             Type of lED, DATA PIN, Color Type RGB/HSV(number of lights)
void setup() { FastLED.addLeds<WS2812,2, RGB>(leds, NUM_LEDS); }

void loop(){ 
  static uint8_t hue; //sets colour
  for(int i = 0; i < NUM_LEDS; i++) {   //cycles through
    // fade everything out
    leds.fadeToBlackBy(40);

    //sets led value
    leds[i] = CHSV( 240, 255, hue++);
    
    FastLED.delay(50);
  }
}

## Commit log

2023-11-03 Prototype Arduino Code
2023-11-03 Prototype Images
2023-11-04 Prototype Progress Report
2023-11-26 6 reader support
    [Circuit-Diagram.fzz]
2023-11-30 LEDs activated by rfid
2023-11-30 Checks for UID match, illuminates reader associated LED on match
